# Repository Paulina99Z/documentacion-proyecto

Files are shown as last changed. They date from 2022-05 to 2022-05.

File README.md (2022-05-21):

# Convergencia luminosa a la contracción mesurada

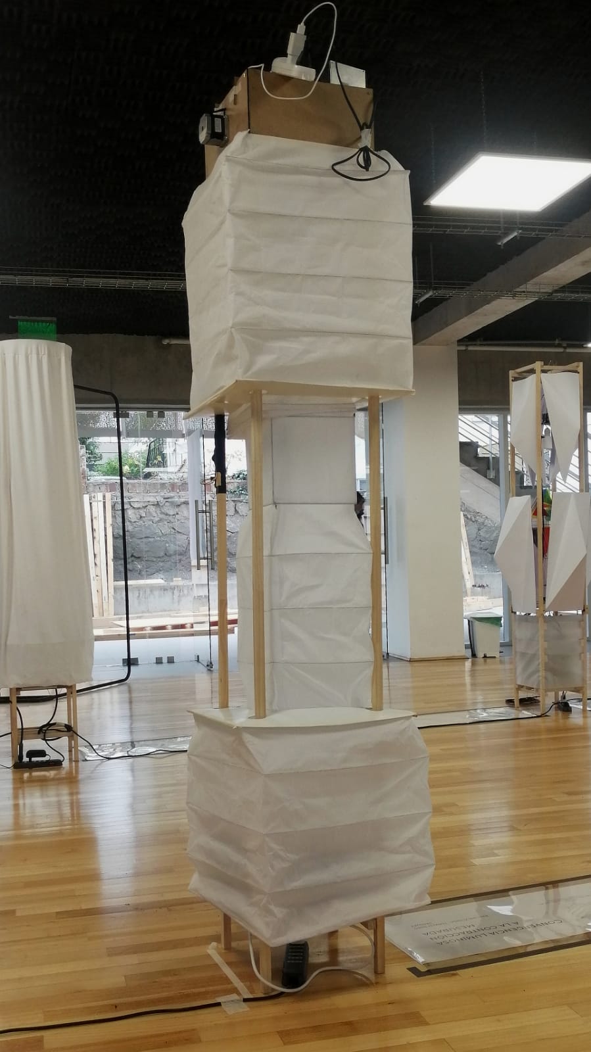
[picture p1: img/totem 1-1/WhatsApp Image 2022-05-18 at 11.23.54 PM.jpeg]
Totem de dia


Este repositorio es la documentación y archivos referentes al proyecto de diseño del ciclo 2 del Taller de Interacción del año 2022, de la escuela de Arquitectura y diseño PUCV. Realizado por Paulina Zúñiga y Natalia Soto entre 06 de Abril y 12 de Mayo.

##  Descripción del proyecto

Cuando se observaba el acto de tomar un objeto, las luces poseen un punto de convergencia que responde a la fuerza del tomar, mientras más sea la contracción, más definidas serán las sombras del cuerpo en cuanto a mostrar un entramado más condensado que cuando la contracción es mínima. El estudio de la mano al sostener un pincel durante la semana de farándula, responde con el dibujo de las sombras al tener la necesidad de hacer unas con líneas homólogas, mientras que el punto de mayor fuerza implica la sobreposición de las líneas del dibujo, mostrando el cuerpo sombra como un ente mucho más compacto. Lo mesurado se encuentra en el conocimiento de un límite de movimiento que no asemeja a un espasmo sino más bien a la familiarización.

Dentro de este agarrar, encontramos también las cualidades de la certeza y la incertidumbre, hay un momento de sorpresa (desconocido) y un momento de conocimiento. Para ello pensamos hacer aparecer luces dentro del cuerpo, que responderían a la cercanía del usuario sin dar aviso anterior ni a su ubicación, ni a su existencia. Distinta será la segunda vez que el usuario de acerque al cuerpo habiéndolo ya conocido.

Un tercer momento permite al usuario controlar el motivo de la iluminación, el absoluto control de aquello que ocurre para con la luz, mas no el movimiento que es continuo. El reconocimiento de su mismo y de lo que se quiere obtener que esta vez sí responde a la intencionalidad segunda que mencionábamos en nuestro acercamiento sobre el gesto.

Por ello el cuerpo posee un momento de movimiento continuo, que abre al juego con el cuerpo. Un momento de acercarse y encontrarse con la característica luz y cómo esta reacciona con el movimiento y un momento de control general el cual debe ser atrapado y/o alcanzado por el usuario.

## Elementos 

En primer lugar están los archivos cad, que corresponden a las piezas cortadas en láser, con terciado de 3mm y al modelo 3d del Elemento tótem.
Además se añade el modelo 3D para una pieza que hará la conexión entre el eje de rotación de poleas para generar el movimiento de compresión y el motor stepper.

Para realizar todas las piezas se utilizaron tecnicas como el origami para los plisados de papel, formas basadas en el libro "Técnicas de corte y plegado para diseñadores", corte en láser e impresión 3D con filamento negro.
Otros elementos de la materialidad incluyen listones de 1pulg x 1pulg, cartón forrado, tarugos de 12mm para los ejes de rotación, alambre para la construcción e hilo capaz de resistir el peso del cuerpo.

Otro aspecto importante del tótem es el uso de programación con sistema ARDUINO. Para nuestro gesto se utiliza un motor stepper que permite el movimiento en el eje Y del tótem, cuyo código esta definido en la carpeta ---. tiras de luces led que se encuienden en cuanto el usuario se acerca en un primer momento al cuerpo. Y, finalmente el poder interactuar al tacto con el cuerpo para poder cambiar el color de aquello que se refleja em el cuerpo.

## Imágenes
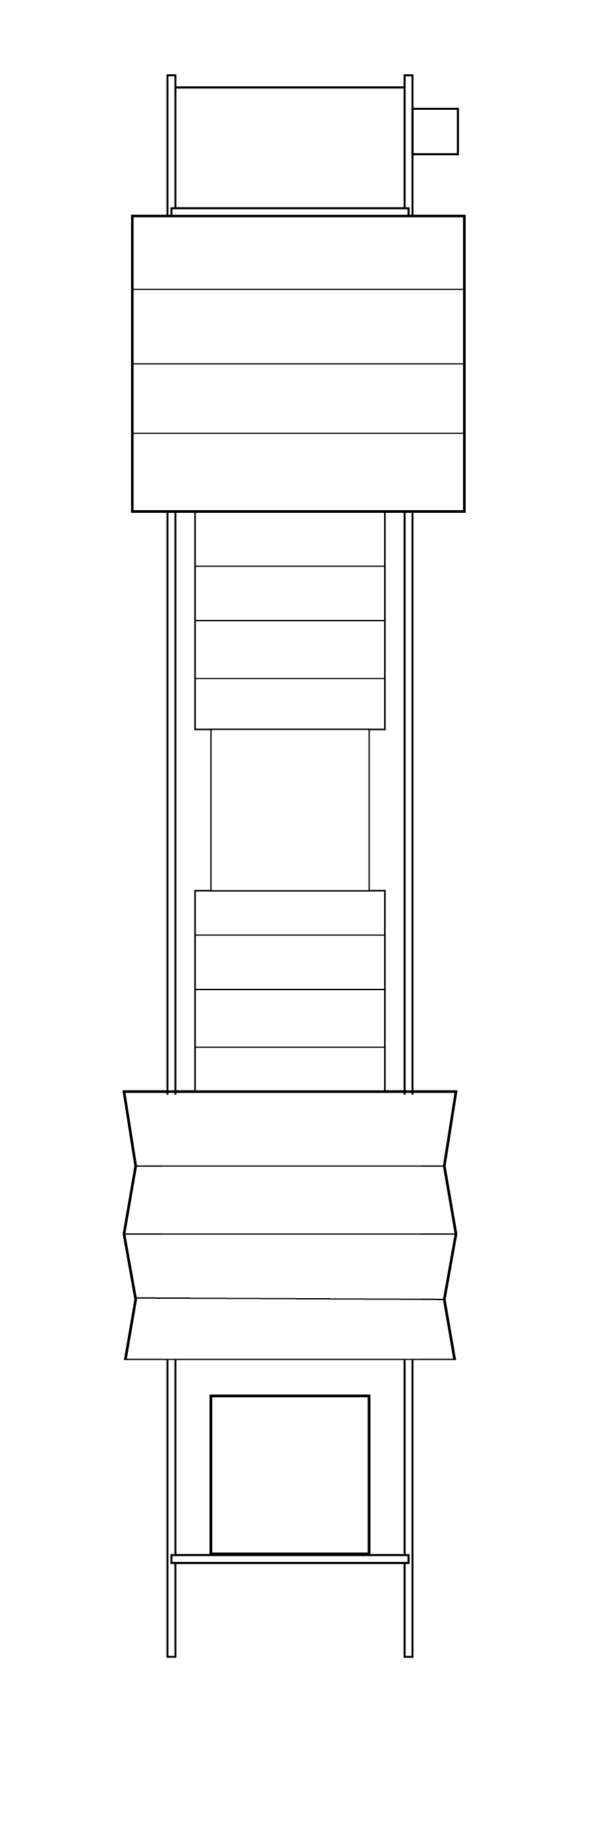
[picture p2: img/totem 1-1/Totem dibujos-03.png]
Dibujo vectorial Vista frontal totem

Totem de dia
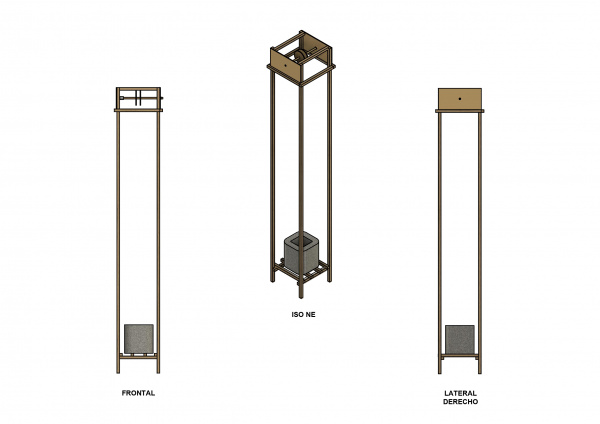
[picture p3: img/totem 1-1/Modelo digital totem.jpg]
Interior totem modelo


## Herramientas y tecnologías
- Impresión 3D con filamento pla negro
- Corte láser, 
- Corte con sierra para listones 1x1
- Arduino
- Fuente de poder 12V

## Estructura de las carpetas
- Archivos de modelado 3d y 2d [Archivos Cad](https://github.com/Paulina99Z/documentacion-proyecto/tree/main/cad)
- Archivos de corte e impresión 3d [Archivos Cam](https://github.com/Paulina99Z/documentacion-proyecto/tree/main/cam)
- Imágenes de registro y contrucción [Imágenes](https://github.com/Paulina99Z/documentacion-proyecto/tree/main/img)
- Programación y conexión Arduino [Archivos Ino](https://github.com/Paulina99Z/documentacion-proyecto/tree/main/ino)

## Registro exposición
<iframe width="640" height = "480" src="https://www.youtube.com/watch?v=4rSVPTRsMz8"> </iframe>
<iframe width="640" height = "480" src="https://youtube.com/shorts/acE36tKqKnE?feature=share"> </iframe>

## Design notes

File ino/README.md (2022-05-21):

# ino
Archivos de Arduino 

Para la construcción utilizamos dos arduinos, un Arduino UNO (Motor) y un arduino ESP32 (Luces). Para la configuración de ambos cabe destacar que la placa ESP32 si bien puede llegar a soportar como máximo 12V (De la fuente de poder que utilizamos) no es recomendable ni una buena práctica hacer directa conexión para suplir de poder a la placa, por ende, es necesario pensar en un modo de reducir el voltaje entre 5V a 7V para así evitar quemarla. En nuestro trabajo, le dimos solución conectándola a un cargador de celular de entrada tradicional que era capaz de suplir 5V desde la conección al sistema de corriente de la sala de exposición.

El motor utilizado es un Motor Paso A Paso Nema 23 de 200 Pasos, el cual necesita una alimentación de energía de 12V y el uso de un driver, en nuestro caso EasyDriver Driver que está diseñado para el uso de estos motores.
El motor fue controlado por un joystick, definiendo solamente el eje X del mismo.
Cables de conexión Macho-macho Hembra-Hembra y Hembra-Macho.
Las luces led utilizadas son Tira Cinta Led 2835 De 10 Mts RGB, una marca genérica que también necesita 12V para su funcionamiento y puede variar en la tonalidad (Uso del color). Estas fueron controladas por un sensor ultrasónico HC-sr04 con una lectura de >30cm.

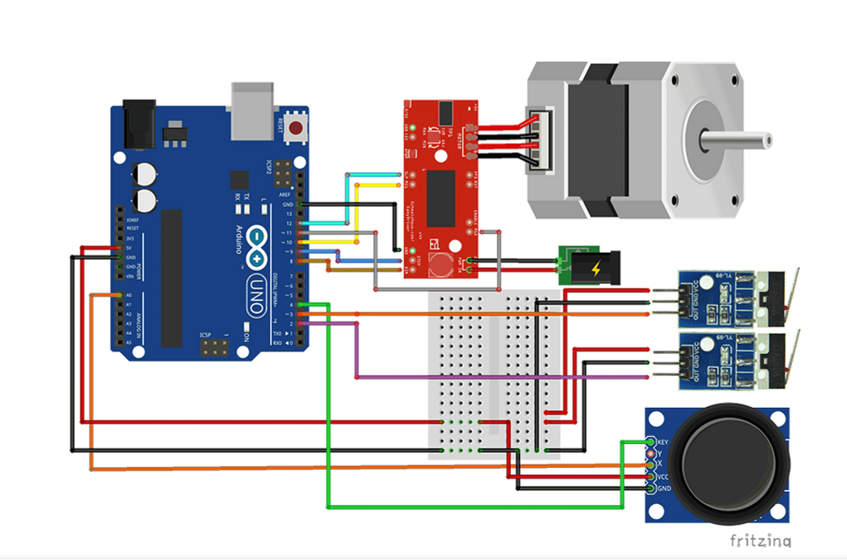
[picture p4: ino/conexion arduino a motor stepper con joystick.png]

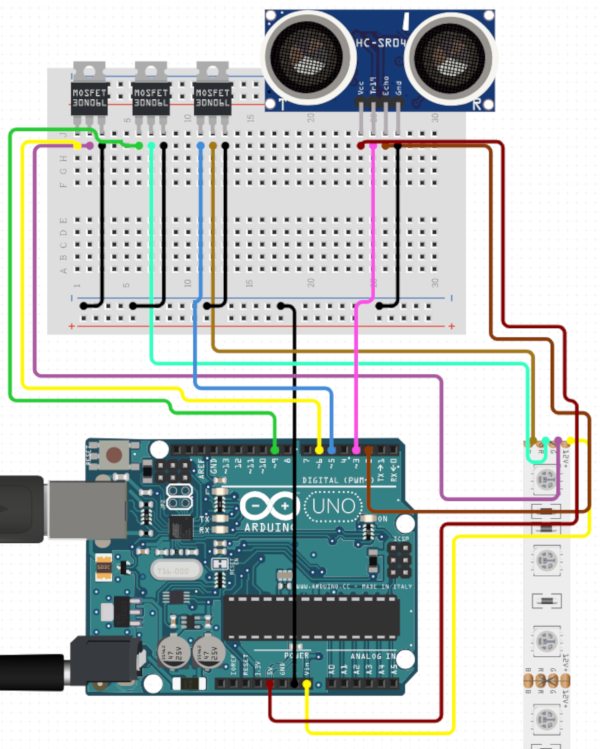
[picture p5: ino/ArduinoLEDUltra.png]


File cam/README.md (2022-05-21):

# cam

Archivos para la fabricación del tótem en corte láser e impresión 3d.
Para los cortes láser utilizamos MDF de 3mm de grosor cortado en láser con las configuraciones 30-70-70, sin pintar, aproximadamente 3 piezas de 40x40 cm; además, para las cajas interiores de los elementos de electrónica, utilizamos cartón madera (corte láser, configuración para cartón duplex).

En el caso de las impresiones 3d, creamos dos piezas para el eje de rotación, una de término y una que sujetará el eje al motor sin tener que indentar el mismo. Para ello utilizamos filamento negro de secado rígido, con debido cuidado especialmente en la pieza al motor pues debe poder permitir la entrada de los prisioneros que harán el sostenido con el eje del motor.

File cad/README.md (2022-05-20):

# cad

Modelos o dibujos, por ejemplo archivos Autocad, Inventor, entre otros. 
El primer archivo refiere a la construcción del cuerpo del totem; para ello se utilizaron junquillos de 1 pulgada x 1 pulgada; unidos entre sí por clavos para de madera de 1 1/2 Pulgada tal que al medio quedaba un cuadrado de 30cm x 30cm con una altura de 2 metros.

El segundo Archivo es la piesa de impresión para ajustar el motor Stepper con el Eje de rotación, esta pensada para un Motor Stepper de 12V, con un eje de rotación de madera de 30 cm cuadrado (1,5cm de grosor). Utiliza prisioneros para mantener el eje del motor sujeto al eje de rotación de la polea.

Por último se tiene el archivo de corte de la polea en terciado de 3mm, ambas ruedas tienen un grosor de 6mm por lo cual es necesario adherir dos caras, las cuales luego se incertarán en el eje de rotación, 1cm desde el centro cada una.

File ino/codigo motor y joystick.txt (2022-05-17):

CODIGO MOTOR Y JOYSTICK (FUNCIONA)

#define step_pin 9  // Pin 9 connected to Steps pin on EasyDriver
#define dir_pin 8   // Pin 8 connected to Direction pin
#define MS1 10       // Pin 10 connected to MS1 pin
#define MS2 11       // Pin 11 connected to MS2 pin
#define SLEEP 12     // Pin 12 connected to SLEEP pin

#define X_pin A0    // Pin A0 connected to joystick x axis
#define Joy_switch 4  // Pin 4 connected to joystick switch

#define Limit01 2  // Pin 2 connected to Limit switch out
#define Limit02 3  // Pin 3 connected to Limit switch out

int step_speed = 1;  // Speed of Stepper motor (higher = slower)

void setup() {
   pinMode(MS1, OUTPUT);
   pinMode(MS2, OUTPUT);
   pinMode(dir_pin, OUTPUT);
   pinMode(step_pin, OUTPUT);
   pinMode(SLEEP, OUTPUT);
   
   pinMode(Limit01, INPUT);
   pinMode(Limit01, INPUT);
   
   pinMode(Joy_switch, INPUT_PULLUP);
   
   digitalWrite(SLEEP, HIGH);  // Wake up EasyDriver
   delay(5);  // Wait for EasyDriver wake up

/* Configure type of Steps on EasyDriver:
// MS1 MS2
//
// LOW LOW = Full Step //
// HIGH LOW = Half Step //
// LOW HIGH = A quarter of Step //
// HIGH HIGH = An eighth of Step //
*/

   digitalWrite(MS1, LOW);      // Configures to Full Steps
   digitalWrite(MS2, LOW);    // Configures to Full Steps
}

void loop() {
  if ( digitalRead(Joy_switch)) {  //  If Joystick switch is clicked
    delay(5);  // delay for deboucing
    switch (step_speed) {  // check current value of step_speed and change it
      case 1:
        step_speed=10;  // slow speed
        break;
      case 3:
        step_speed=10;  // fast speed
        break;
      case 10:
        step_speed=10;  // medium speed
        break;
    }
  }    
    
  if (analogRead(X_pin) > 712) {  //  If joystick is moved Left
    if (digitalRead(Limit01)) {}  // check if limit switch is activated
    
      else {  //  if limit switch is not activated, move motor clockwise
      
        digitalWrite(dir_pin, LOW);  // (HIGH = anti-clockwise / LOW = clockwise)
        digitalWrite(step_pin, HIGH);
        delay(step_speed);
        digitalWrite(step_pin, LOW);
        delay(step_speed);
    }      
  }
  
    if (analogRead(X_pin) < 312) {  // If joystick is moved right
    
    if (digitalRead(Limit02)) {}  // check if limit switch is activated
    
      else {  //  if limit switch is not activated, move motor counter clockwise
      
        digitalWrite(dir_pin, HIGH);  // (HIGH = anti-clockwise / LOW = clockwise)
        digitalWrite(step_pin, HIGH);
        delay(step_speed);
        digitalWrite(step_pin, LOW);
        delay(step_speed);
    }      
  }
}

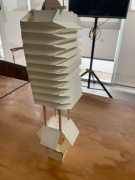
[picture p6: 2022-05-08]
img/maqueta 1-5/prototipo 3/Propuesta3MaquetaNataliaSotoPaulinaZuñiga12022TDI3.jpeg

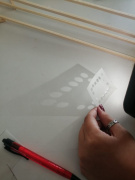
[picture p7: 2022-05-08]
img/maqueta 1-5/prototipo 1/135px-Propuesta1MaquetaNataliaSotoPaulinaZuñiga12022TDI5.jpeg

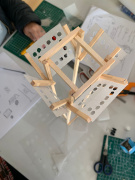
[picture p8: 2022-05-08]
img/maqueta 1-5/prototipo 1/Propuesta1MaquetaNataliaSotoPaulinaZuñiga12022TDI2.jpeg

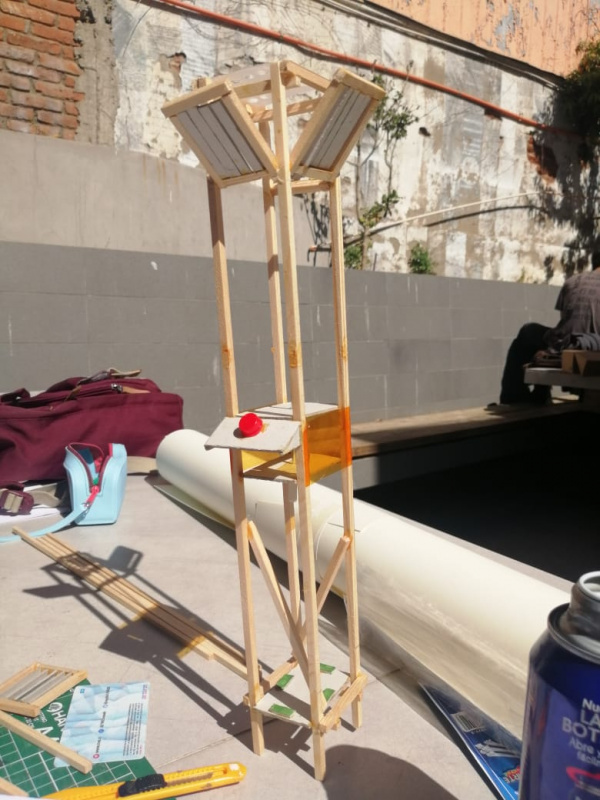
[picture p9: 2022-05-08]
img/maqueta 1-5/prototipo 1/Propuesta1MaquetaNataliaSotoPaulinaZuñiga12022TDI4.jpeg

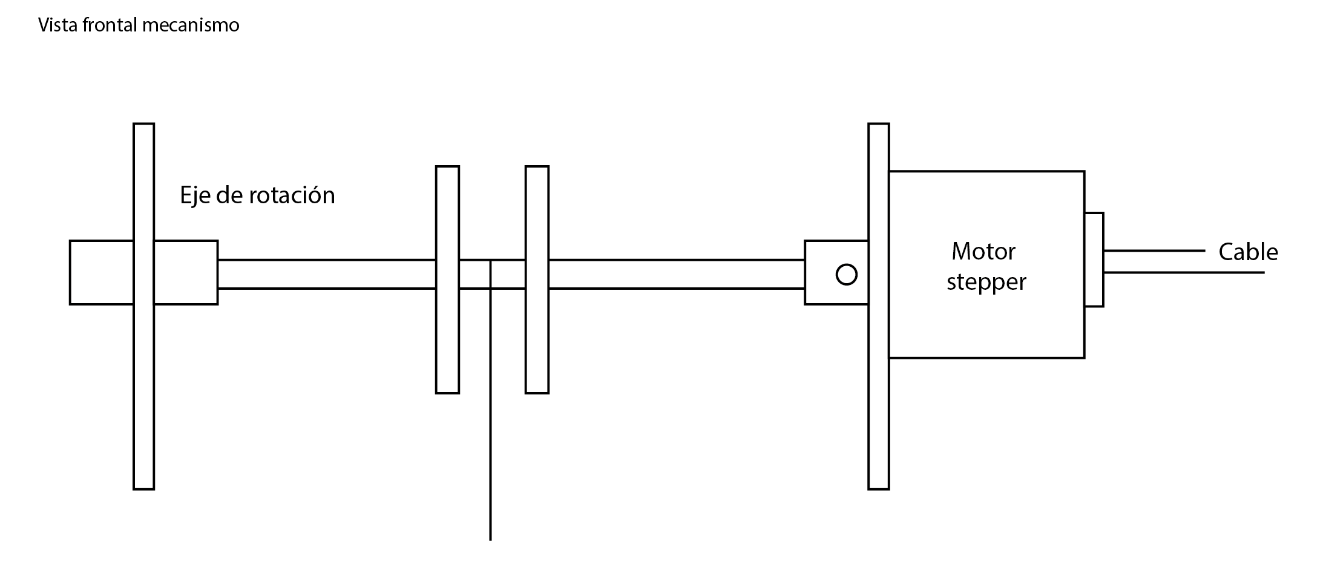
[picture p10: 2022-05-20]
img/totem 1-1/Totem dibujos-01.png

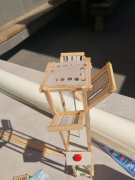
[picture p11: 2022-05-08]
img/maqueta 1-5/prototipo 1/135px-Propuesta1MaquetaNataliaSotoPaulinaZuñiga12022TDI6.jpeg

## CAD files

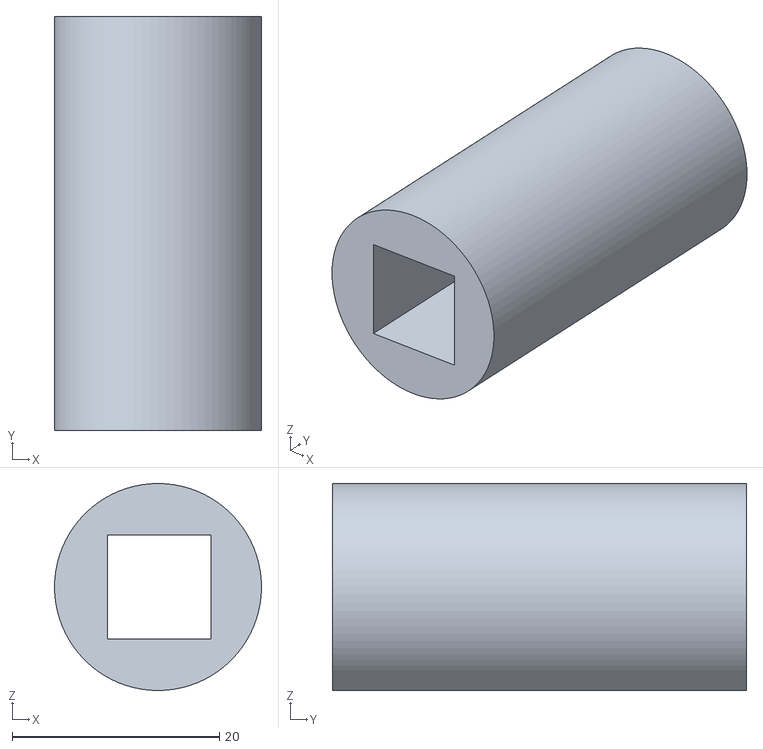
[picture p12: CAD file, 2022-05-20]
cam/pieza para que ruede v1.stl
20.0 x 40.0 x 20.0

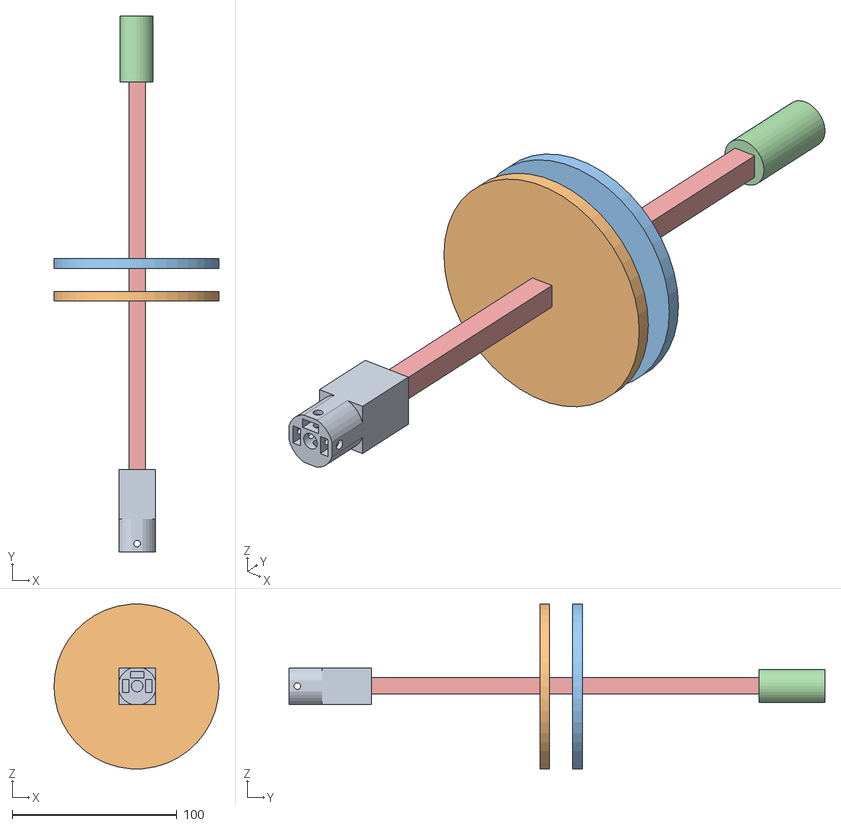
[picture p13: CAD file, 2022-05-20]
cam/polea con eje cuadrado v2.obj
100.0 x 324.7 x 99.7

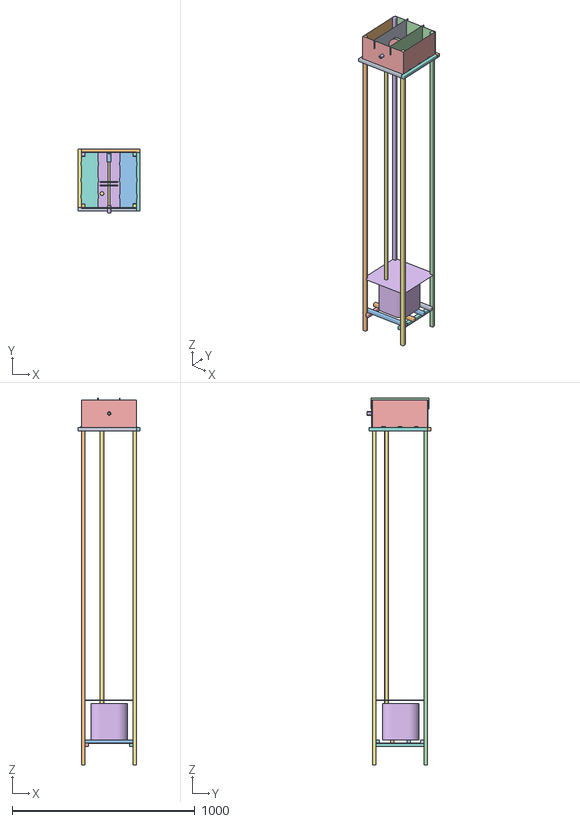
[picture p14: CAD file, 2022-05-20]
cam/estructura totem terminado.obj
338.3 x 348.4 x 2010.7

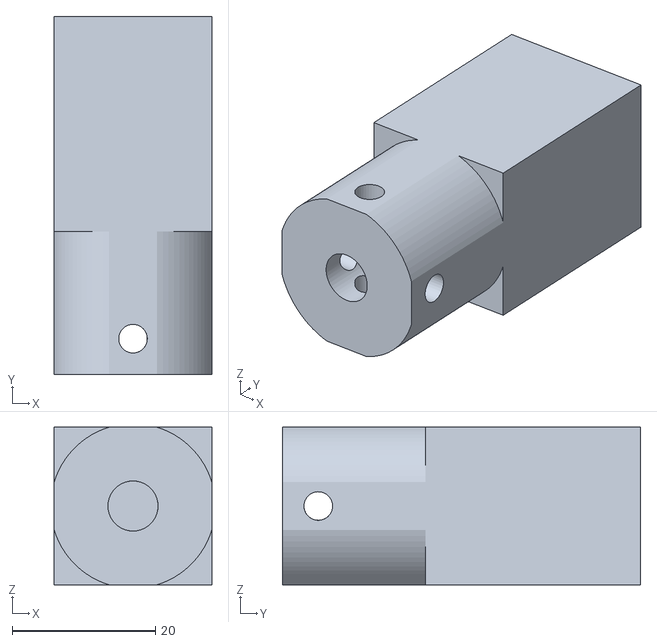
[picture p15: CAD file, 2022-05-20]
cam/PIEZA PARA PRISIONEROS v1.stl
22.0 x 50.0 x 22.0

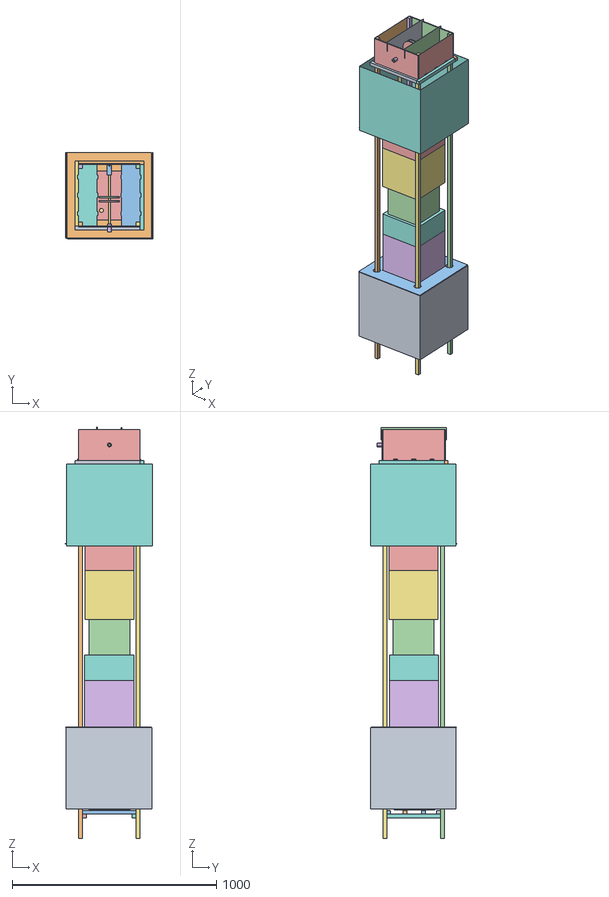
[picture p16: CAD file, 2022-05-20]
cam/cuerpo de papel.obj
426.0 x 421.8 x 2010.7

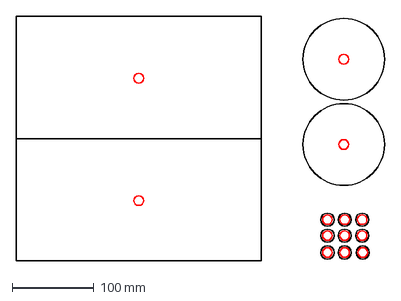
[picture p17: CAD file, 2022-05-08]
cam/polea archivo de corte.dxf
451.3 x 300.0 mm

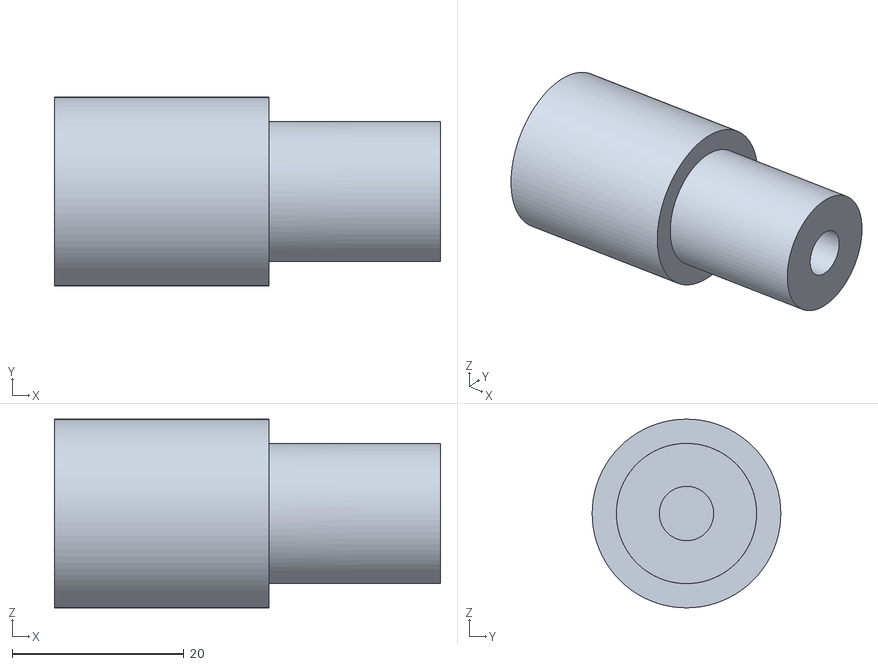
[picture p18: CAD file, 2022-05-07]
cam/pieza motor s v0.stl
45.0 x 22.0 x 22.0

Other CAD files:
cad/polea archivo de corte.dwg
cad/esqueleto totem v5.f3z
cad/pieza motor para impresion 3D v1.f3d

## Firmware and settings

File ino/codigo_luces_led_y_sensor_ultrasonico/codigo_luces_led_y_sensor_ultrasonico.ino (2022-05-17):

#define RED_PIN 25
#define GREEN_PIN 26
#define BLUE_PIN 32
#define echoPin 13
#define trigPin 12
//   # of milliseconds to pause between each pass of the main Arduino loop
#define Loop_Delay 1

float duration, distance;

  
//brightness level of each color (0..255)
  int Brightness_R;
  int Brightness_G;
  int Brightness_B;
//fade step counter for LED cycle through off (510 steps), fade on (255 steps),
//    on (510 steps), fade off (255 steps) 1530 total steps
  int FadeStep_R;  
  int FadeStep_G;
  int FadeStep_B;
//number of times LED has completed a full fade cycle
//  int CycleCountB; 
//  int CycleCountR;
//  int CycleCountG;
//used to establish what values to send to LED strip  
//  int ColorValue;
// =====================================
// ARDUINO SETUP ROUTINE
// -------------------------------------
void setup() {
  pinMode(trigPin, OUTPUT);
  pinMode(echoPin, INPUT);
  
  Serial.begin(9600);
  
//Serial.begin(9600);
  pinMode(RED_PIN, OUTPUT);
  pinMode(GREEN_PIN, OUTPUT);
  pinMode(BLUE_PIN, OUTPUT);
  
//set initial strip color. 0(off) to 255(on). can be anything or nothing. 
//This value is constrained to 0 - 255. any number higher than 255 will be rounded down to 255.
//                                      any number lower than 0 will be rounded up to 0.
  Brightness_R = 0;
  Brightness_G = 0;
  Brightness_B = 0;
 
//Set starting fade step position. -764 to -255 = on (brightness level is 255)
//                                 -254 to 0 = fading on (this number *-1 = brightness level)
//                                 0 to 510 = off (brightness level is 0)
//                                 511 to 765 = fading off (this number - 510 = brightness level
//must each be 510 steps apart for smooth color pauses. 
//if pauses removed by commenting out or removing ColorValue if statements and rplacing 
//with setLEDS (Brightness_R, Brightness_G, Brightness_B); ,which I've already done, these number 
//can be any value from -764 to 765 in any combantion, likely making many unplesant fade patterns,
//but also with many possibilities for interesting patterns.  If all values are 510 steps apart   
//the results will ROY G BIV either forward or backward and starting at different positions 
//depending on the values given. the farther off the 510 steps of seperationg the further from
//ROY G BIV the pattern will move.
  FadeStep_R = 0;      //0      These setting for normal ROY G BIV
  FadeStep_G = 325;    //510
  FadeStep_B = 650;    //-510
//Set each LED's fade cycle counter to 0
//  CycleCountB = 0;
//  CycleCountR = 0;
//  CycleCountG = 0;
}
 
// =====================================
// ARDUINO MAIN LOOP ROUTINE
// -------------------------------------
void loop() {
   digitalWrite(trigPin, LOW);
  delayMicroseconds(2);
  digitalWrite(trigPin, HIGH);
  delayMicroseconds(10);
  digitalWrite(trigPin, LOW);

  duration = pulseIn(echoPin, HIGH);
  distance = (duration*.0343)/2;
  Serial.print("Distance: ");
  Serial.println(distance);
  delay(100);

  if (distance< 40) {
//decrement each LED's fade step counter by one at the start of each loop
    FadeStep_R = FadeStep_R - 1;
    FadeStep_G = FadeStep_G - 1;
    FadeStep_B = FadeStep_B - 1;
    
//fade red LED according to it's fade step counter.         
 if (FadeStep_R == -764) {FadeStep_R = 765;}
 if (FadeStep_R < 0) {Brightness_R = FadeStep_R * -1;}  
 if (FadeStep_R >= 510) {Brightness_R = FadeStep_R - 510;}
// if (FadeStep_R == -510) {CycleCountR = CycleCountR + 1;} //count + 1 for each full fade cycle
 
//fade green LED according to it's fade step counter.      
 if (FadeStep_G == -764) {FadeStep_G = 765;}
 if (FadeStep_G < 0) {Brightness_G = FadeStep_G * -1;}  
 if (FadeStep_G >= 510) {Brightness_G = FadeStep_G - 510;}
// if (FadeStep_G == -510) {CycleCountG = CycleCountG + 1;} //count + 1 for each full fade cycle
 
//fade blue LED according to it's fade step counter.  
 if (FadeStep_B == -764) {FadeStep_B = 765;}
 if (FadeStep_B < 0) {Brightness_B = FadeStep_B * -1;}  
 if (FadeStep_B >= 510) {Brightness_B = FadeStep_B - 510;}
// if (FadeStep_B == -510) {CycleCountB = CycleCountB + 1;} // count + 1 for each full fade cycle
  
//  if step counters are intialized 510 steps appart, -510 is the step in each LED's fade cycle
//  that it will be on full brightness while the other 2 LED's are off. 
 
    Brightness_B = constrain(Brightness_B, 0, 255);
    Brightness_G = constrain(Brightness_G, 0, 255);
    Brightness_R = constrain(Brightness_R, 0, 255); 
 
// if (CycleCountB == 8) {CycleCountB = 0;}  
// if (CycleCountR == 8) {CycleCountR = 0;}
// if (CycleCountG == 8) {CycleCountG = 0;}
    
// if (CycleCountR == 2) {ColorValue = 1 ;} //set point for pattern to pause on red
// if (CycleCountR > 2) {ColorValue = 0;}   
 
// if (CycleCountG == 4) {ColorValue = 2;}   //set point for pattern to pause on green
// if (CycleCountG > 4) {ColorValue = 0;}
  
// if (CycleCountB == 6) {ColorValue = 3;}   //set point for pattern to pause on blue
// if (CycleCountB > 6) {ColorValue = 0;}
 
//Send brightness levels to LED strip
setLEDS (Brightness_R, Brightness_G, Brightness_B);
// if (ColorValue == 0) {setLEDS (Brightness_R, Brightness_G, Brightness_B);} // default to fade pattern
// if (ColorValue == 1) {setLEDS (255, 0, 0);}  //LED strip red
// if (ColorValue == 2) {setLEDS (0, 255, 0);}  //LED strip green
// if (ColorValue == 3) {setLEDS (0, 0, 255);}  //LED strip blue
     
 //    slow the loop down a bit
    delay (Loop_Delay);
    }
    else  {setLEDS(0,0,0);}
 

} 
 //    send the LED levels to the Arduino pins
 void setLEDS (int ipR, int ipG, int ipB) {
  analogWrite (RED_PIN, ipR);     // send the red brightness level to the red LED's pin
  analogWrite (GREEN_PIN, ipG);
  analogWrite (BLUE_PIN, ipB);}

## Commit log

2022-05-07 Archivos para impresión 3D
    [pieza motor para impresion 3D v1.f3d, pieza motor s v0.stl]
2022-05-08 fotos de diferentes iteraciones
2022-05-08 prueba de img
2022-05-08 archivos cad y cam
    [esqueleto totem v5.f3z, polea archivo de corte.dwg, polea archivo de corte.dxf]
2022-05-08 archivos carpeta ino
    [pieza motor para impresion 3D v1.f3d]
2022-05-20 modelos 3D
    [PIEZA PARA PRISIONEROS v1.stl, cuerpo de papel.obj, estructura totem terminado.obj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]
